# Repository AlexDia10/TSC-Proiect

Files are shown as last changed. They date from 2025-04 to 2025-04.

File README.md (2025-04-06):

# TSC-Proiect

## Schema Bloc



## Bill Of Materials

| Parts | Qty | CHECK_PRICE | DATASHEET |
|---|-----|---|---|
| CHG_LED | 1 | | |
| R1_PINH1, R2_PINH1 | 2 | | |
| S1 | 1 | | |
| EPD_C5 | 1 | | |
| R3 | 1 | | |
| R1_PWRUSB | 1 | | |
| C1, C2, C4_USB, C6, C8, C9, C10, C6_DELAY | 8 | | |
| C3 | 1 | | |
| R4-R10, R_BOOT, R_CHANGE, R_C1, R_RESET| 11  | | |
| C7 | 1 | | |
| J4 | 1 | | |
| R_CAPACITOR | 1 | | |
| C5 | 1 | | |
| EPD_C1–EPD_C12 | 9 | | |
| R2 | 1 | | |
| R1_BAT | 1 | | |
| Q1, Q2 | 2 | | |
| R2_BAT | 1 | | |
| C5_USB | 1 | | |
| C1_BAT, C2_BAT | 4 | | |
| C4 | 1 | | |
| R2-USB, R2-USB1 | 2 | | |
| L1 | 1 | | |
| IC1 | 1 | | |
| BOOT_BUTTON, CHANGE_BUTTON, RESET_BUTTON | 3 | | |
| C10_SUPERCAP | 1 | [SnapEDA](https://www.snapeda.com/parts/PC5H225/Vishay/view-part/?ref=eda) | |
| U3 | 1 | [SnapEDA](https://www.snapeda.com/parts/DS3231SN%23/Analog+Devices/view-part/?ref=eda) | |
| U2 | 1 | [SnapEDA](https://www.snapeda.com/parts/ESP32-C6-WROOM-1-N8/Espressif+Systems/view-part/?ref=eda) | |
| PFMF.050.1 | 1 | | [Datasheet](http://datasheets.avx.com/schottky.pdf) |
| D2, D7 | 2 | | |
| SENSOR2 | 1 | | |
| MCP73831 | 1 | | |
| J1 | 1 | [SnapEDA](https://www.snapeda.com/parts/MAX17048GT10/Analog+Devices/view-part/?ref=eda) | |
| U4 | 1 | [SnapEDA](https://www.snapeda.com/parts/MBR0530/Onsemi/view-part/?ref=eda) | |
| D3, D4, D5 | 3 | [SnapEDA](https://www.snapeda.com/parts/PG81010603MR/Littelfuse/view-part/?ref=eda) | |
| D6, D8–D12 | 6 | | |
| J3 | 1 | | |
| J2 | 1 | [SnapEDA](https://www.snapeda.com/parts/SI1308EDL-T1-GE3/Vishay+Siliconix/view-part/?ref=eda) | |
| Q3 | 1 | | |
| TP1–TP17 | 17  | | |
| D1 | 1 | [SnapEDA](https://www.snapeda.com/parts/USBLC6-2SC6Y/STMicroelectronics/view-part/?ref=eda) | |
| U1 | 1 | [SnapEDA](https://www.snapeda.com/parts/W25Q512JV/Winbond+Electronics/view-part/?ref=eda) | |
| IC4 | | | |

## Specificații Hardware

**🔹 1. Microcontroller – ESP32-C6-WROOM-1-N8**

**CPU:** RISC-V 32-bit, 160 MHz (single-core)

**Memorie:** 320KB SRAM, 512KB ROM, 8MB Flash SPI (W25Q512JVEIQ)

**Conectivitate:** Wi-Fi 6 (300 Mbps), Bluetooth 5 LE (Mesh), Zigbee 3.0

**Periferice:** 4×SPI, 2×I²C, 2×UART, USB 2.0 OTG

**Consum:** 80 mA activ, 1.5 mA sleep, 20 µA deep sleep

**Wake-up:** GPIO, RTC, UART, senzor BME680

**🔹 2. Alimentare**

**Încărcare:** MCP73831 (100–500 mA), LED stare (GPIO18)

**LDO:** BD5229G-TR (eficiență 92%, ripple <50mV)

**Fuel Gauge:** MAX17048 (±1% SOC, alertă critică, 7 µA consum)

**🔹 3. Senzori**

**BME680 (I²C, 0x76):** temp., umiditate, presiune, VOC/eCO₂

Algoritm IAQ (BSEC), compensare termică, calibrare din fabrică

**RTC – DS3231SN#:** ±2ppm, backup cu supercondensator, alarmă, square wave

**🔹 4. Afișaj E-Ink** – 7.5", 800×480 px

**Interfață:** SPI + CS/DC/RST/BUSY

**Consum:** 15–25 mA la refresh, 0 mA static

**Avantaj:** imagine persistentă fără consum

**🔹 5. Interfețe & Stocare**

**USB-C:** alimentare, serial console, DFU update (ESD + Polyfuse 500 mA)

**Qwiic I²C:** extensii senzori/modul

**MicroSD:** loguri/fișiere, SPI/SD

**Flash externă:** W25Q512JVEIQ (quad SPI, aplicații mari)

**🔹 6. Interacțiune**

**Butoane:** 3× tactile (navigare/selectare/back), debouncing HW/SW

**🔹 7. Interfețe Utilizate**

Interfață	Componente
SPI	E-Ink, Flash, SD Card
I²C	BME680, MAX17048, DS3231, Qwiic
GPIO	Butoane, control display
USB	Alimentare, date

## Alocarea pinilor pentru ESP32-C6

| Pin ESP32-C6 | Componentă / Semnal | Descriere |
|---|---|---|
| GPIO1 | I²C SDA (BME680, MAX17048, DS3231, Qwiic) | Linie de date partajată pentru toți senzorii și RTC-ul conectați la magistrala I²C. |
| GPIO2 | I²C SCL (BME680, MAX17048, DS3231, Qwiic) | Linie de clock utilizată pentru sincronizarea comunicației I²C. |
| GPIO5 | SPI MISO (E-Paper) | Primește date de la afișajul E-Paper prin interfața SPI. |
| GPIO6 | SPI MOSI (E-Paper) | Trimite date către afișajul E-Paper prin interfața SPI. |
| GPIO7 | SPI CLK (E-Paper) | Semnal de clock pentru sincronizarea comunicației SPI cu afișajul. |
| GPIO8 | SPI CS (E-Paper) | Semnal Chip Select pentru activarea afișajului E-Paper. |
| GPIO9 | E-Paper DC (Data/Command) | Selectează între trimiterea de date sau comenzi către afișaj. |
| GPIO10 | E-Paper RST | Reset hardware pentru afișajul E-Paper. |
| GPIO11 | E-Paper BUSY | Indică dacă afișajul este ocupat și nu poate primi comenzi. |
| GPIO12 | Button #1 | Buton de control, ex: „Pagina următoare”. |
| GPIO13 | Button #2 | Buton de control, ex: „Pagina anterioară”. |
| GPIO14 | Button #3 | Buton de control, ex: „Meniu” sau „Selectare”. |
| GPIO15 | MAX17048 ALERT (opțional) | Semnal de alertă de la senzorul de baterie (ex: baterie descărcată). |
| GPIO16 | USB D+ (intern la USB PHY) | Linie de semnal diferențial pozitiv pentru conexiunea USB 2.0. |
| GPIO17 | USB D- (intern la USB PHY) | Linie de semnal diferențial negativ pentru conexiunea USB 2.0. |
| GPIO18 | LED de status (opțional) | LED pentru indicarea stărilor (Wi-Fi, încărcare etc.). |
| GPIO19 | SD Card CS (opțional) | Semnal Chip Select pentru cardul microSD. |
| GPIO20 | SD Card MISO (opțional) | Linie de recepție a datelor de la cardul microSD. |
| GPIO21 | SD Card MOSI (opțional) | Linie de transmisie a datelor către cardul microSD. |
| GPIO4 | SD Card CLK (opțional) | Semnal de clock pentru comunicația SPI cu cardul microSD. |

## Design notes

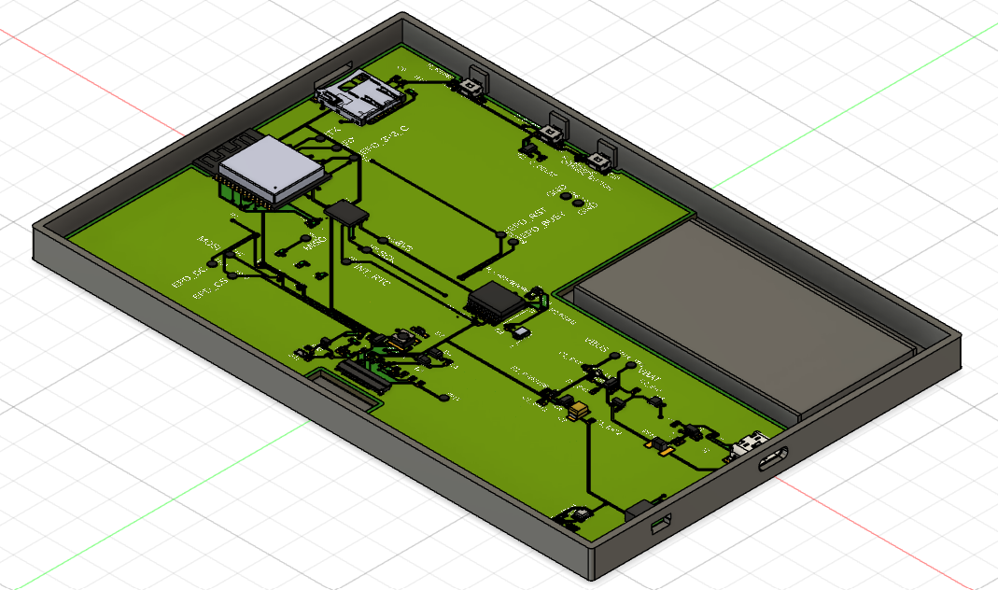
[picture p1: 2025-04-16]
Images/Enclosure.png

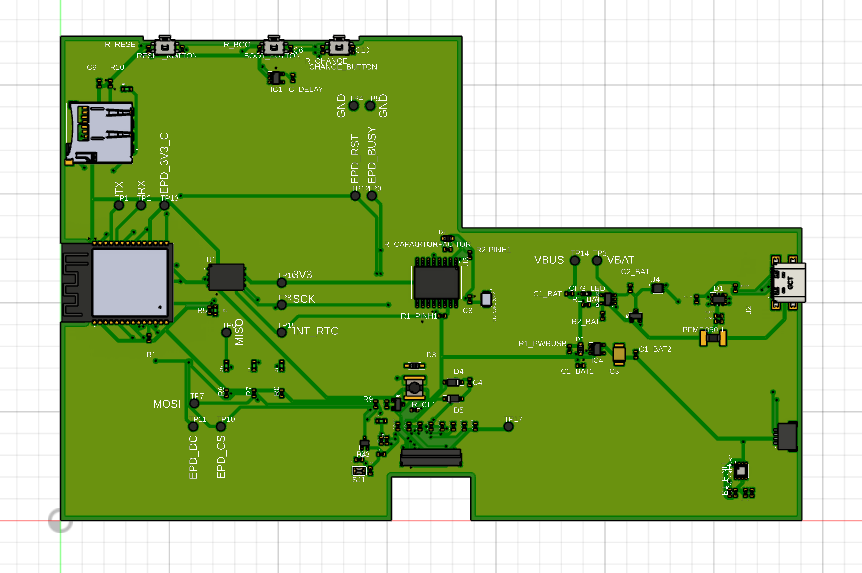
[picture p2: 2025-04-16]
Images/PCB 3D.png

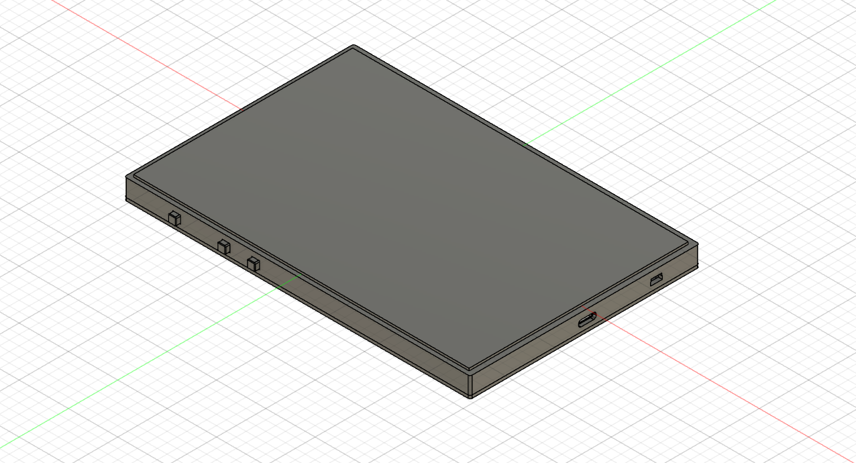
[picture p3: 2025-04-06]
Images/E-bookReader.png

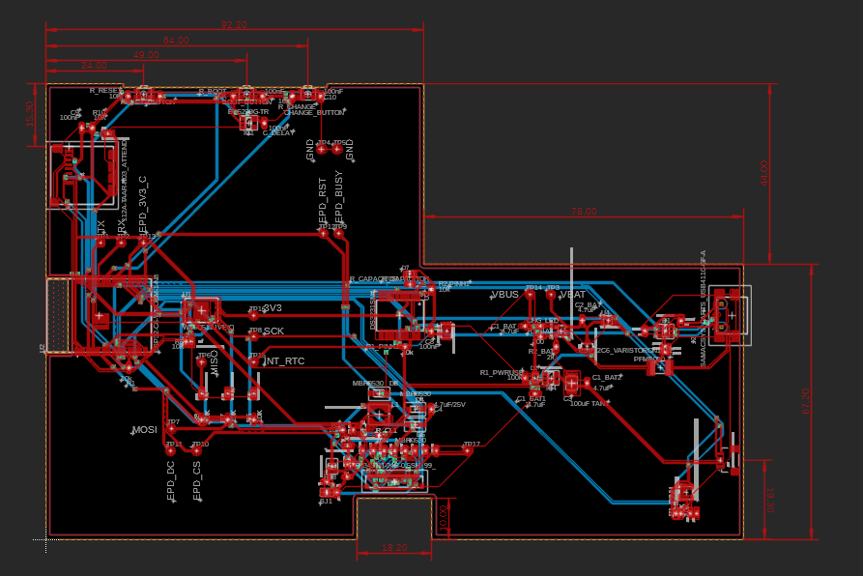
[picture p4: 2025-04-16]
Images/PCB 2D.png

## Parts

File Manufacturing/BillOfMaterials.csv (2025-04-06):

Qty | Value | Device | Package | Parts | Description | ARROW_PART_NUMBER | ARROW_PRICE-STOCK | AVAILABILITY | CENTROID_NOT_SPECIFIED | CHECK_PRICES | COPYRIGHT | DATASHEET | DESCRIPTION | DIGIKEY_DESCRIPTION | DIGIKEY_PART_NUMBER | HEIGHT | LEAD_FREE | MANUFACTURER_NAME | MANUFACTURER_PART_NUMBER | MF | MFR_NAME | MOUSER_PART_NUMBER | MOUSER_PRICE-STOCK | MOUSER_TESTING_PART_NUMBER | MOUSER_TESTING_PRICE-STOCK | MP | MPN | PACKAGE | POPULARITY | PREFIX | PRICE | PROD_ID | PURCHASE-URL | ROHS | SNAPEDA_LINK | SPICEMODEL | SPICEPREFIX | TEMPERATURE_RANGE_HIGH | TEMPERATURE_RANGE_LOW | TP_SIGNAL_NAME | VALUE
1 |  | ADAFRUIT_LEDCHIP-LED0603 | ADAFRUIT_CHIP-LED0603 | CHG_LED | LED
2 |  | ESP32_WROVER_EAGLE-LTSPICE_RR0402 | ESP32_WROVER_EAGLE-LTSPICE_R0402 | R1_PINH, R2-PINH | RESISTOR, European symbol |  |  |  |  |  |  |  |  |  |  |  |  |  |  |  |  |  |  |  |  |  |  |  |  |  |  |  |  |  |  | NONE | R
1 |  | SJ | SJ | SJ1 | SMD solder JUMPER |  |  |  |  |  |  |  |  |  |  |  |  |  |  |  |  |  |  |  |  |  |  |  | 3
1 | 0.1uF/50V | EAGLE-LTSPICE_CC0402 | EAGLE-LTSPICE_C0402 | EPD_C5 | CAPACITOR, European symbol |  |  |  |  |  |  |  |  |  |  |  |  |  |  |  |  |  |  |  |  |  |  |  |  |  |  |  |  |  |  | NONE | C
1 | 0.47 | ESP32_WROVER_EAGLE-LTSPICE_RR0402 | ESP32_WROVER_EAGLE-LTSPICE_R0402 | R3 | RESISTOR, European symbol |  |  |  |  |  |  |  |  |  |  |  |  |  |  |  |  |  |  |  |  |  |  |  |  |  |  |  |  |  |  | NONE | R
1 | 100k | ESP32_WROVER_EAGLE-LTSPICE_RR0402 | ESP32_WROVER_EAGLE-LTSPICE_R0402 | R1_PWRUSB | RESISTOR, European symbol |  |  |  |  |  |  |  |  |  |  |  |  |  |  |  |  |  |  |  |  |  |  |  |  |  |  |  |  |  |  | NONE | R
8 | 100nF | EAGLE-LTSPICE_CC0402 | EAGLE-LTSPICE_C0402 | C1, C2, C4_USB, C6, C8, C9, C10, C_DELAY | CAPACITOR, European symbol |  |  |  |  |  |  |  |  |  |  |  |  |  |  |  |  |  |  |  |  |  |  |  |  |  |  |  |  |  |  | NONE | C
1 | 100uF TANT | RCL_CPOL-EUCT3528 | RCL_CT3528 | C3 | POLARIZED CAPACITOR, European symbol |  |  |  |  |  |  |  |  |  |  |  |  |  |  |  |  |  |  |  |  |  |  |  | 0 |  |  |  |  |  |  |  | C
11 | 10K | ESP32_WROVER_EAGLE-LTSPICE_RR0402 | ESP32_WROVER_EAGLE-LTSPICE_R0402 | R4, R5, R6, R7, R8, R9, R10, R_BOOT, R_CHANGE, R_CL1, R_RESET | RESISTOR, European symbol |  |  |  |  |  |  |  |  |  |  |  |  |  |  |  |  |  |  |  |  |  |  |  |  |  |  |  |  |  |  | NONE | R
3 | 10k | ESP32_WROVER_EAGLE-LTSPICE_RR0402 | ESP32_WROVER_EAGLE-LTSPICE_R0402 | R1, R1_PINH1, R2-PINH1 | RESISTOR, European symbol |  |  |  |  |  |  |  |  |  |  |  |  |  |  |  |  |  |  |  |  |  |  |  |  |  |  |  |  |  |  | NONE | R
1 | 10uF | EAGLE-LTSPICE_CC0402 | EAGLE-LTSPICE_C0402 | C7 | CAPACITOR, European symbol |  |  |  |  |  |  |  |  |  |  |  |  |  |  |  |  |  |  |  |  |  |  |  |  |  |  |  |  |  |  | NONE | C
1 | 112A-TAAR-R03_ATTEND | 112A-TAAR-R03_ATTEND | 112ATAARR03ATTEND | J4 | Micro SD Card Socket, Push-Push Type, Top Mount, SMT, H=1.83mm, 10u |  |  |  |  |  |  |  | Micro SD Card Socket | Push-Push Type | Top Mount | SMT | H=1.83mm | 10u |  |  | 1.9mm |  | ATTEND | 112A-TAAR-R03 ATTEND
1 | 15 | ESP32_WROVER_EAGLE-LTSPICE_RR0402 | ESP32_WROVER_EAGLE-LTSPICE_R0402 | R_CAPACITOR | RESISTOR, European symbol |  |  |  |  |  |  |  |  |  |  |  |  |  |  |  |  |  |  |  |  |  |  |  |  |  |  |  |  |  |  | NONE | R
1 | 1uF | EAGLE-LTSPICE_CC0402 | EAGLE-LTSPICE_C0402 | C5 | CAPACITOR, European symbol |  |  |  |  |  |  |  |  |  |  |  |  |  |  |  |  |  |  |  |  |  |  |  |  |  |  |  |  |  |  | NONE | C
9 | 1uF/50V | EAGLE-LTSPICE_CC0402 | EAGLE-LTSPICE_C0402 | EPD_C1, EPD_C2, EPD_C6, EPD_C7, EPD_C8, EPD_C9, EPD_C10, EPD_C11, EPD_C12 | CAPACITOR, European symbol |  |  |  |  |  |  |  |  |  |  |  |  |  |  |  |  |  |  |  |  |  |  |  |  |  |  |  |  |  |  | NONE | C
1 | 2.2 | ESP32_WROVER_EAGLE-LTSPICE_RR0402 | ESP32_WROVER_EAGLE-LTSPICE_R0402 | R2 | RESISTOR, European symbol |  |  |  |  |  |  |  |  |  |  |  |  |  |  |  |  |  |  |  |  |  |  |  |  |  |  |  |  |  |  | NONE | R
1 | 200 | ESP32_WROVER_EAGLE-LTSPICE_RR0402 | ESP32_WROVER_EAGLE-LTSPICE_R0402 | R1_BAT | RESISTOR, European symbol |  |  |  |  |  |  |  |  |  |  |  |  |  |  |  |  |  |  |  |  |  |  |  |  |  |  |  |  |  |  | NONE | R
2 | 20V/4.2A/52m?/1.4W | ESP32_WROVER_SPARKFUN-DISCRETESEMI_MOSFET_PCH-DMG2305UX-7 | ESP32_WROVER_SPARKFUN-DISCRETESEMI_SOT23-3 | Q1, Q2 | P-channel MOSFETs |  |  |  |  |  |  |  |  |  |  |  |  |  |  |  |  |  |  |  |  |  |  |  |  |  |  | TRAN-14388 |  |  |  |  |  |  |  |  | 20V/4.2A/52m?/1.4W
1 | 2k | ESP32_WROVER_EAGLE-LTSPICE_RR0402 | ESP32_WROVER_EAGLE-LTSPICE_R0402 | R2_BAT | RESISTOR, European symbol |  |  |  |  |  |  |  |  |  |  |  |  |  |  |  |  |  |  |  |  |  |  |  |  |  |  |  |  |  |  | NONE | R
1 | 4.7 uF | EAGLE-LTSPICE_CC0402 | EAGLE-LTSPICE_C0402 | C5_USB | CAPACITOR, European symbol |  |  |  |  |  |  |  |  |  |  |  |  |  |  |  |  |  |  |  |  |  |  |  |  |  |  |  |  |  |  | NONE | C
4 | 4.7uF | EAGLE-LTSPICE_CC0402 | EAGLE-LTSPICE_C0402 | C1_BAT, C1_BAT1, C1_BAT2, C2_BAT | CAPACITOR, European symbol |  |  |  |  |  |  |  |  |  |  |  |  |  |  |  |  |  |  |  |  |  |  |  |  |  |  |  |  |  |  | NONE | C
1 | 4.7uF/25V | EAGLE-LTSPICE_CC0402 | EAGLE-LTSPICE_C0402 | C4 | CAPACITOR, European symbol |  |  |  |  |  |  |  |  |  |  |  |  |  |  |  |  |  |  |  |  |  |  |  |  |  |  |  |  |  |  | NONE | C
2 | 5k1 | ESP32_WROVER_EAGLE-LTSPICE_RR0402 | ESP32_WROVER_EAGLE-LTSPICE_R0402 | R2-USB, R2-USB1 | RESISTOR, European symbol |  |  |  |  |  |  |  |  |  |  |  |  |  |  |  |  |  |  |  |  |  |  |  |  |  |  |  |  |  |  | NONE | R
1 | 744043680IND_4828-WE-TPC_WRE | 744043680IND_4828-WE-TPC_WRE | IND_4828-WE-TPC_WRE | L1 |  |  |  |  |  |  | Copyright (C) 2024 Ultra Librarian. All rights reserved. |  |  |  |  |  |  |  | 744043680 |  | Wurth Electronics
1 | BD5229G-TR | BD5229G-TR | SOT95P280X125-5N | IC1 | Voltage Detector with Adjustable Delay Time: CMOS processes are utilized to develop high precision, low current consumption CMOS reset ICs that allow arbitrary setting of the delay time. The extensive lineup includes both Nch Open Drain and CMOS output types in a wide range of detection voltages (from 2.3V to 6.0V, in 0.1V steps), enabling selection of the ideal solution based on customer requirements. In addition, the entire series is of course both lead-free and RoHS-compliant. |  |  |  |  |  |  |  | Voltage Detector with Adjustable Delay Time: CMOS processes are utilized to develop high precision | low current consumption CMOS reset ICs that allow arbitrary setting of the delay time. The extensive lineup includes both Nch Open Drain and CMOS output types in a wide range of detection voltages (from 2.3V to 6.0V | in 0.1V steps) | enabling selection of the ideal solution based on customer requirements. In addition | the entire series is of course both lead-free and RoHS-compliant. |  |  | 1.25mm |  | ROHM Semiconductor | BD5229G-TR |  |  | 755-BD5229G-TR | https://www.mouser.co.uk/ProductDetail/ROHM-Semiconductor/BD5229G-TR?qs=4kLU8WoGk0vvnhrrYwdszw%3D%3D
3 | BUTTON_CUSYOMV1 | BUTTON_CUSYOMV1 | MYBUTTON | BOOT_BUTTON, CHANGE_BUTTON, RESET_BUTTON
1 | CPH3225A | CPH3225A | CAPCP3225X100N | C10_SUPERCAP | Cap 0.011F 3.3V 1210 Flat Check availability |  |  | Not in stock |  | https://www.snapeda.com/parts/CPH3225A/Seiko+Instruments/view-part/?ref=eda |  |  | 11 mF (EDLC) Supercapacitor 3.3 V 1210 (3225 Metric) - - |  |  |  |  |  |  | Seiko Instruments |  |  |  |  |  | CPH3225A |  | 1210 Seiko |  |  | None |  | https://www.snapeda.com/api/url_track_click_mouser/?unipart_id=562593&manufacturer=Seiko Instruments&part_name=CPH3225A&search_term=None |  | https://www.snapeda.com/parts/CPH3225A/Seiko+Instruments/view-part/?ref=snap
1 | DS3231SN# | DS3231SN# | SOIC127P1032X265-16N | U3 | Real Time Clock Serial 16-Pin SOIC W T/R Check availability |  |  | In Stock |  | https://www.snapeda.com/parts/DS3231SN%23/Analog+Devices/view-part/?ref=eda |  |  | Extremely Accurate I2C-Integrated RTC/TCXO/Crystal |  |  |  |  |  |  | Analog Devices |  |  |  |  |  | DS3231SN# |  | SOIC-16 Maxim |  |  | None |  | https://www.snapeda.com/api/url_track_click_mouser/?unipart_id=99048&manufacturer=Analog Devices&part_name=DS3231SN#&search_term=None |  | https://www.snapeda.com/parts/DS3231SN%23/Analog+Devices/view-part/?ref=snap
1 | ESP32-C6-WROOM-1-N8 | ESP32-C6-WROOM-1-N8 | XCVR_ESP32-C6-WROOM-1-N8 | U2 | Check availability |  |  | In Stock |  | https://www.snapeda.com/parts/ESP32-C6-WROOM-1-N8/Espressif+Systems/view-part/?ref=eda |  |  | Multiprotocol Modules ESP32-C6 module | Wi-Fi 6 in 2.4 GHz band | Bluetooth 5 | Zigbee 3.0 and Thread. ESP34-WROOM Compatible - ENGINEERING SAMPLE |  |  |  |  |  |  | Espressif Systems |  |  |  |  |  | ESP32-C6-WROOM-1-N8 |  | None |  |  | None |  |  |  | https://www.snapeda.com/parts/ESP32-C6-WROOM-1-N8/Espressif+Systems/view-part/?ref=snap
1 | ESP32C6_VARISTORCN1812 | ESP32C6_VARISTORCN1812 | ESP32C6_VARISTOR_CT/CN1812 | PFMF.050.1 | VARISTOR |  |  |  |  |  |  |  |  |  |  |  |  |  |  |  |  |  |  |  |  |  |  |  | 0
2 | ESP32_WROVER_AVX---SD0805S020S1R0_AVX_SD0805S020S1R0_0_0AVX_SD0805S020S1R0_0_0 | ESP32_WROVER_AVX---SD0805S020S1R0_AVX_SD0805S020S1R0_0_0AVX_SD0805S020S1R0_0_0 | ESP32_WROVER_AVX---SD0805S020S1R0_AVX_SD0805S020S1R0_0 | D2, D7 | Schottky Barrier Rectifier Diode |  |  |  | No |  |  | http://datasheets.avx.com/schottky.pdf |  | DIODE SCHOTTKY 20V 1A 0805 | 478-7800-1-ND |  | yes |  |  | AVX |  | 581-SD0805S020S1R0 |  |  |  |  |  | 0805 (2012 metric) |  | D |  |  |  | yes |  |  |  | +125°C | -55°C
1 | ESP32_WROVER_BME680_BME680 | ESP32_WROVER_BME680_BME680 | ESP32_WROVER_BME680_PSON80P300X300X100-8N | SENSOR2 | Integrated Environmental Unit |  |  | Unavailable |  |  |  |  | Integrated Environmental Unit |  |  |  |  |  |  | Bosch Sensortec |  |  |  |  |  | BME680 |  | LGA-8 Bosch Tools |  |  | None
1 | ESP32_WROVER_SPARKFUN-IC-POWER_MCP73831 | ESP32_WROVER_SPARKFUN-IC-POWER_MCP73831 | ESP32_WROVER_SPARKFUN-IC-POWER_SOT23-5 | MCP73831 | MCP73831T Li-Ion, Li-Pol Controller |  |  |  |  |  |  |  |  |  |  |  |  |  |  |  |  |  |  |  |  |  |  |  |  |  |  | IC-09995
1 | FH34SRJ-24S-0.5SH_99_ | FH34SRJ-24S-0.5SH_99_ | FH34SRJ24S05SH99 | J1 | (0.50mm) Surface Mount, Right Angle |  |  |  |  |  |  |  | 24 Position FFC | FPC Connector Contacts | (0.50mm) Surface Mount | Right Angle |  |  | 1.1mm |  | Hirose | FH34SRJ-24S-0.5SH(99) |  |  | 798-FH34SRJ24S05SH99 | https://www.mouser.co.uk/ProductDetail/Hirose-Connector/FH34SRJ-24S-0.5SH99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
1 | MAX17048G+T10 | MAX17048G+T10 | SON50P200X200X80-9N | U4 | Check availability |  |  | In Stock |  | https://www.snapeda.com/parts/MAX17048G+T10/Analog+Devices/view-part/?ref=eda |  |  | 3µA 1-Cell/2-Cell Fuel Gauge with ModelGauge |  |  |  |  |  |  | Analog Devices |  |  |  |  |  | MAX17048G+T10 |  | TDFN-8 Maxim |  |  | None |  | https://www.snapeda.com/api/url_track_click_mouser/?unipart_id=329239&manufacturer=Analog Devices&part_name=MAX17048G+T10&search_term=None |  | https://www.snapeda.com/parts/MAX17048G+T10/Analog+Devices/view-part/?ref=snap
3 | MBR0530 | MBR0530 | SOD3716X135N | D3, D4, D5 | ON SEMICONDUCTOR - MBR0530 - DIODE, SCHOTTKY, 0.5A, 30V, SOD-123 |  |  | In Stock |  | https://www.snapeda.com/parts/MBR0530/Onsemi/view-part/?ref=eda |  |  | Diode Schottky 30 V 500mA Surface Mount SOD-123 |  |  |  |  |  |  | ON Semiconductor |  |  |  |  |  | MBR0530 |  | SOD-123-2 ON Semiconductor |  |  | None |  | https://www.snapeda.com/api/url_track_click_mouser/?unipart_id=179458&manufacturer=ON Semiconductor&part_name=MBR0530&search_term=None |  | https://www.snapeda.com/parts/MBR0530/Onsemi/view-part/?ref=snap
6 | PGB1010603MR | PGB1010603MR | DIOC1608X36N | D6, D8, D9, D10, D11, D12 | Check availability |  |  | In Stock |  | https://www.snapeda.com/parts/PGB1010603MR/Littelfuse/view-part/?ref=eda |  |  | 150V (Typ) Clamp - Ipp Tvs Diode Surface Mount 0603 (1608 Metric) |  |  |  |  |  |  | Littelfuse Inc. |  |  |  |  |  | PGB1010603MR |  | 0603 Littelfuse Inc. |  |  | None |  | https://www.snapeda.com/api/url_track_click_mouser/?unipart_id=5659453&manufacturer=Littelfuse Inc.&part_name=PGB1010603MR&search_term=None |  | https://www.snapeda.com/parts/PGB1010603MR/Littelfuse/view-part/?ref=snap
1 | QWIIC_RIGHT_ANGLE | QWIIC_CONNECTORJS-1MM | JST04_1MM_RA | J3 | SparkFun I2C Standard Qwiic Connector |  |  |  |  |  |  |  |  |  |  |  |  |  |  |  |  |  |  |  |  |  |  |  |  |  |  | CONN-13694 |  |  |  |  |  |  |  |  | QWIIC_RIGHT_ANGLE
1 | SAMACSYS_PARTS_USB4110-GF-A | SAMACSYS_PARTS_USB4110-GF-A | SAMACSYS_PARTS_USB4110GFA | J2 | CONN USB 2.0 TYPE-C R/A SMT |  |  |  |  |  |  |  | CONN USB 2.0 TYPE-C R/A SMT |  |  | 3.26mm |  | GCT (GLOBAL CONNECTOR TECHNOLOGY) | USB4110-GF-A |  |  | 640-USB4110-GF-A | https://www.mouser.co.uk/ProductDetail/GCT/USB4110-GF-A?qs=KUoIvG%2F9IlYiZvIXQjyJeA%3D%3D
1 | SI1308EDL-T1-GE3 | SI1308EDL-T1-GE3 | SOT65P210X110-3N | Q3 | MOSFET N-Ch 30V 1.5A TrenchFET SC70 Vishay Si1308EDL-T1-GE3 N-channel MOSFET Transistor, 1.5 A, 30 V, 3-Pin SC-70 |  |  | In Stock |  | https://www.snapeda.com/parts/SI1308EDL-T1-GE3/Vishay+Siliconix/view-part/?ref=eda |  |  | Si1308EDL-T1-GE3 N-channel MOSFET Transistor | 1.5 A | 30 V | 3-Pin SC-70 | Siliconix / Vishay SI1308EDL-T1-GE3 |  |  |  |  |  |  | Vishay Siliconix |  |  |  |  |  | SI1308EDL-T1-GE3 |  | SOT-323 Vishay Semiconductor |  |  | None |  | https://www.snapeda.com/api/url_track_click_mouser/?unipart_id=274603&manufacturer=Vishay Siliconix&part_name=SI1308EDL-T1-GE3&search_term=None |  | https://www.snapeda.com/parts/SI1308EDL-T1-GE3/Vishay+Siliconix/view-part/?ref=snap
17 | TPTP20R | TPTP20R | TP20R | TP1, TP2, TP3, TP4, TP5, TP6, TP7, TP8, TP9, TP10, TP11, TP12, TP13, TP14, TP15, TP16, TP17 | Test pad |  |  |  |  |  |  |  |  |  |  |  |  |  |  |  |  |  |  |  |  |  |  |  | 2
1 | USBLC6-2SC6Y | USBLC6-2SC6Y | SOT95P280X145-6N | D1 | Low Cap. ESD Protection Auto SOT-23-6 STMicroelectronics USBLC6-2SC6Y, Dual Uni-Directional TVS Diode Array, 6-Pin SOT-23 |  |  | In Stock |  | https://www.snapeda.com/parts/USBLC6-2SC6Y/STMicroelectronics/view-part/?ref=eda |  |  | 17V Clamp 5A (8/20µs) Ipp Tvs Diode Surface Mount SOT-23-6 |  |  |  |  |  |  | STMicroelectronics |  |  |  |  |  | USBLC6-2SC6Y |  | SOT-23-6 STMicroelectronics |  |  | None |  |  |  | https://www.snapeda.com/parts/USBLC6-2SC6Y/STMicroelectronics/view-part/?ref=snap
1 | W25Q512JVEIQ | W25Q512JVEIQ | SON127P600X800X80-9N | U1 | Check availability |  |  | In Stock |  | https://www.snapeda.com/parts/W25Q512JVEIQ/Winbond+Electronics/view-part/?ref=eda |  |  | FLASH - NOR Memory IC 512Mb (64M x 8) SPI - Quad I/O 133 MHz 8-WSON (8x6) |  |  |  |  |  |  | Winbond Electronics |  |  |  |  |  | W25Q512JVEIQ |  | Package |  |  | None |  |  |  | https://www.snapeda.com/parts/W25Q512JVEIQ/Winbond+Electronics/view-part/?ref=snap
1 | XC6220A331MR-G | XC6220A331MR-G | SOT95P280X120-5N | IC4 | LDO Voltage Regulators |  |  |  |  |  |  |  | LDO Voltage Regulators |  |  | 1.2mm |  | Torex | XC6220A331MR-G |  |  | 865-XC6220A331MR-G | https://www.mouser.co.uk/ProductDetail/Torex-Semiconductor/XC6220A331MR-G?qs=AsjdqWjXhJ8ZSWznL1J0gg%3D%3D

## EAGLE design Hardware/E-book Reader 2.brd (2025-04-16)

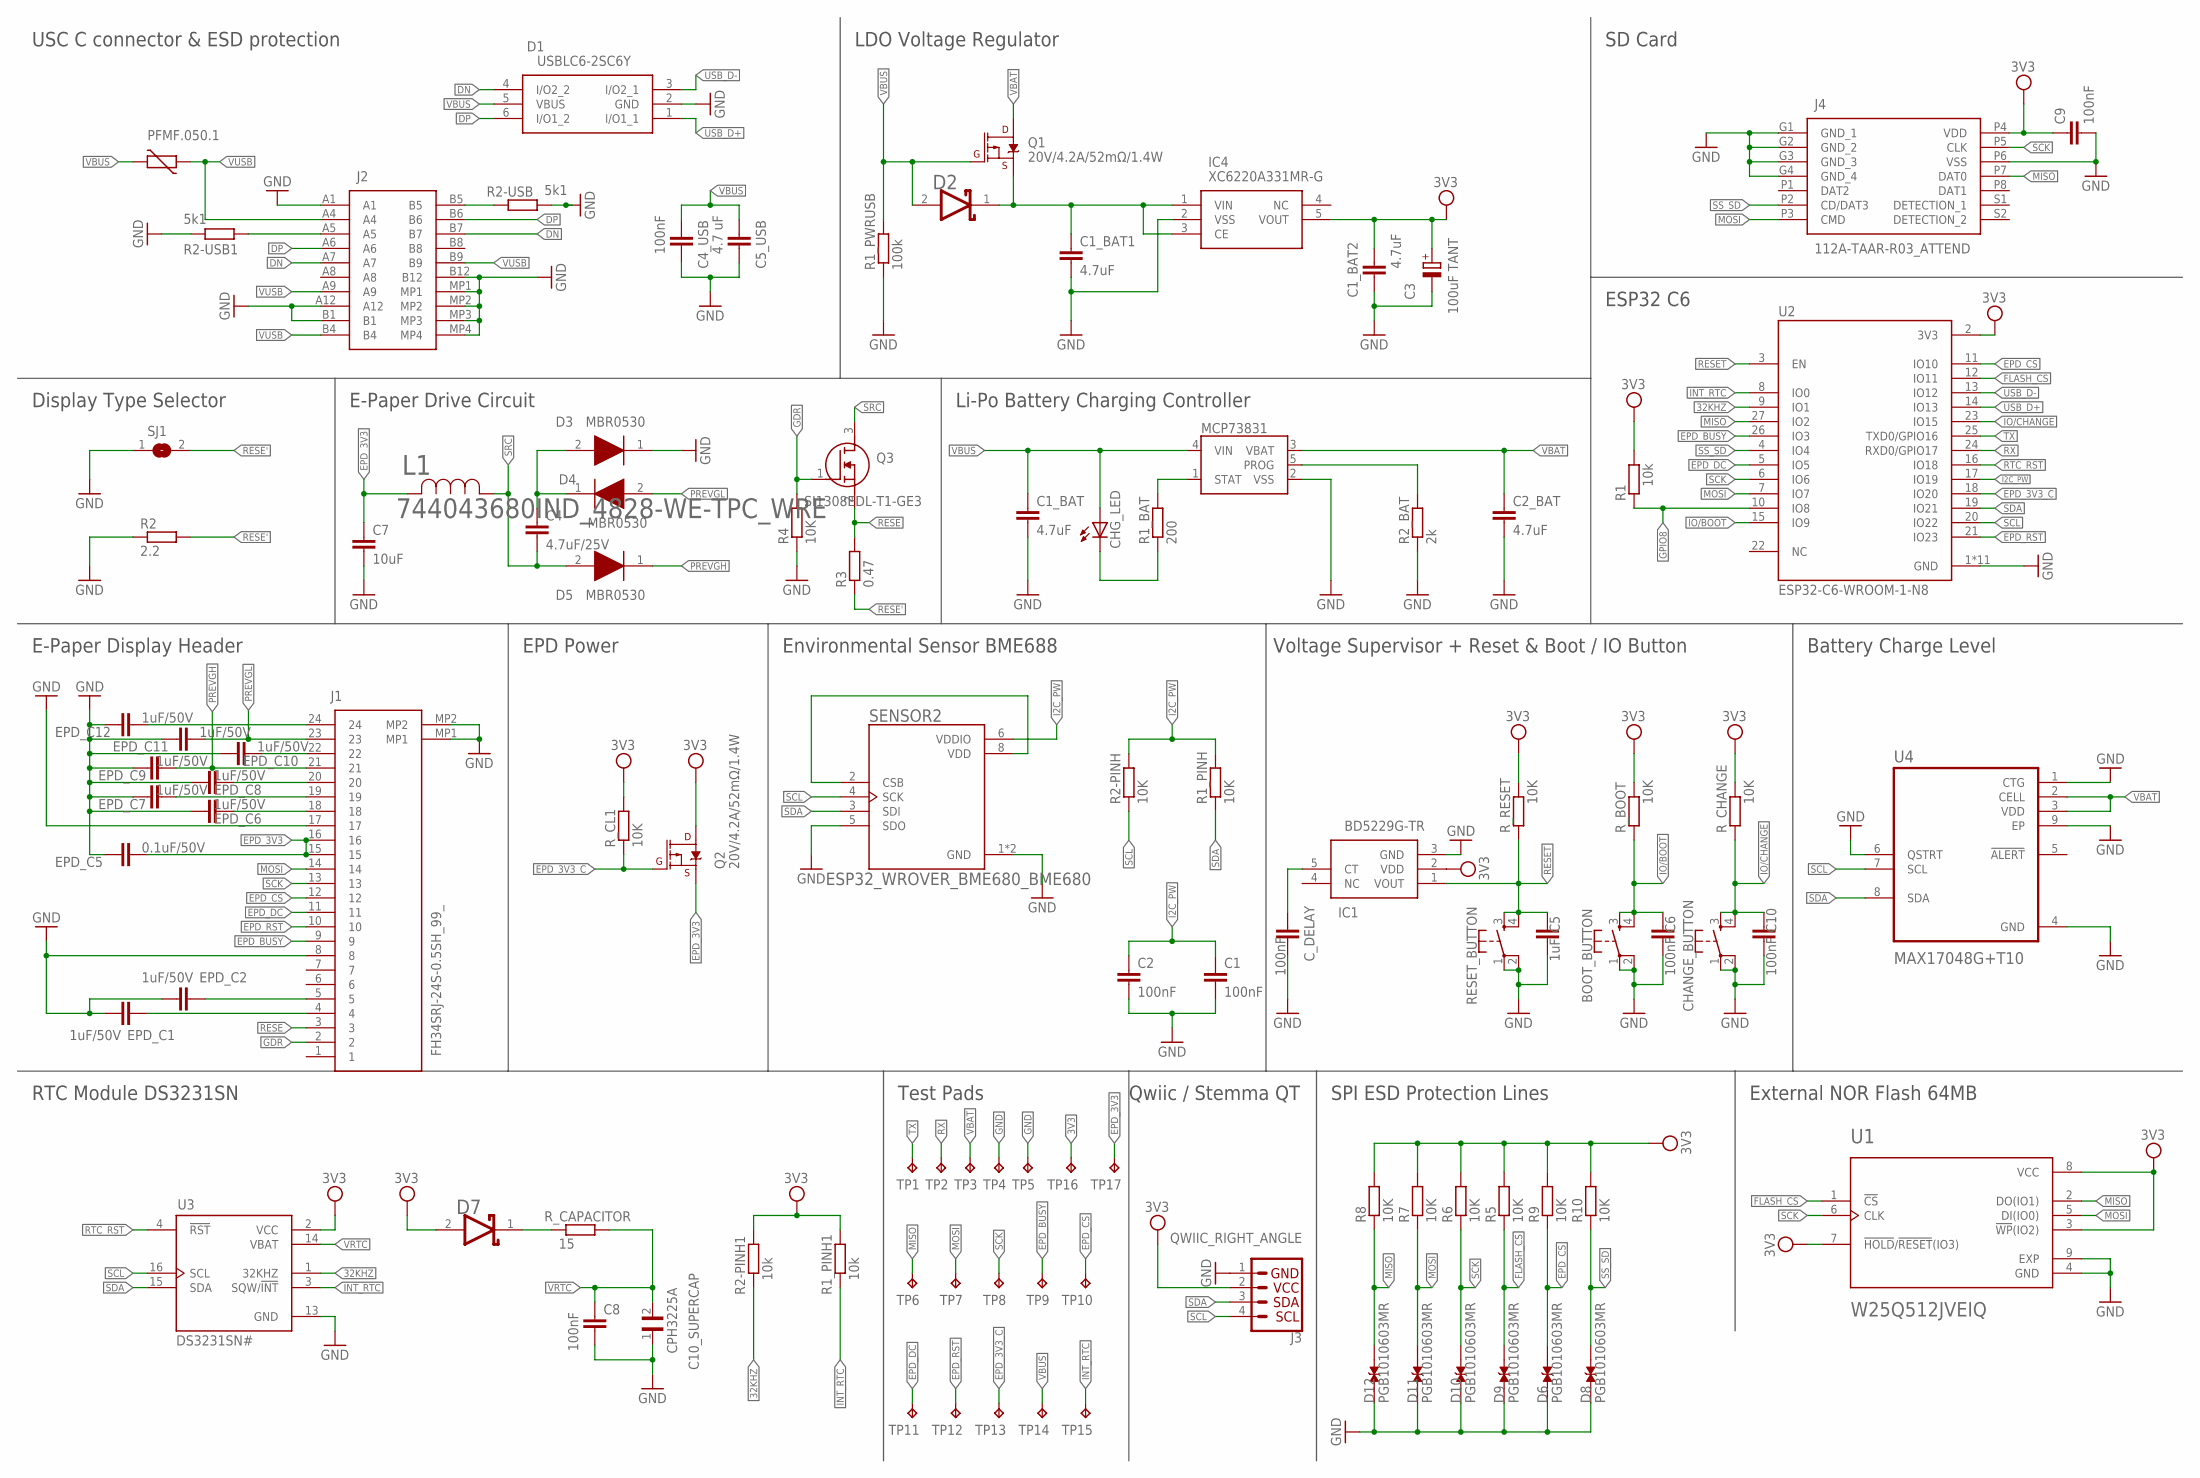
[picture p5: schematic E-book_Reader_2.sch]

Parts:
BOOT_BUTTON: BUTTON_CUSYOMV1; MYBUTTON
C1, C2, C4_USB, C6, C8, C9, C10: 100nF; EAGLE-LTSPICE_C0402
C1_BAT, C1_BAT1, C1_BAT2, C2_BAT: 4.7uF; EAGLE-LTSPICE_C0402
C3: 100uF TANT; RCL_CT3528
C4: 4.7uF/25V; EAGLE-LTSPICE_C0402
C5: 1uF; EAGLE-LTSPICE_C0402
C5_USB: 4.7 uF; EAGLE-LTSPICE_C0402
C7: 10uF; EAGLE-LTSPICE_C0402
C10_SUPERCAP: CPH3225A; CAPCP3225X100N
CHANGE_BUTTON: BUTTON_CUSYOMV1; MYBUTTON
CHG_LED: ADAFRUIT_LEDCHIP-LED0603; ADAFRUIT_CHIP-LED0603
C_DELAY: 100nF; EAGLE-LTSPICE_C0402
D1: USBLC6-2SC6Y; SOT95P280X145-6N
D2, D7: ESP32_WROVER_AVX---SD0805S020S1R0_AVX_SD0805S020S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; ESP32_WROVER_AVX---SD0805S020S1R0_AVX_SD0805S020S1R0_0
D3, D4, D5: MBR0530; SOD3716X135N
D6, D8, D9, D10, D11, D12: PGB1010603MR; DIOC1608X36N
EPD_C1, EPD_C2, EPD_C6, EPD_C7, EPD_C8, EPD_C9, EPD_C10, EPD_C11, EPD_C12: 1uF/50V; EAGLE-LTSPICE_C0402
EPD_C5: 0.1uF/50V; EAGLE-LTSPICE_C0402
IC1: BD5229G-TR; SOT95P280X125-5N
IC4: XC6220A331MR-G; SOT95P280X120-5N
J1: FH34SRJ-24S-0.5SH_99_; FH34SRJ24S05SH99
J2: SAMACSYS_PARTS_USB4110-GF-A; SAMACSYS_PARTS_USB4110GFA
J3: QWIIC_RIGHT_ANGLE; JST04_1MM_RA
J4: 112A-TAAR-R03_ATTEND; 112ATAARR03ATTEND
L1: 744043680IND_4828-WE-TPC_WRE; IND_4828-WE-TPC_WRE
MCP73831: ESP32_WROVER_SPARKFUN-IC-POWER_MCP73831; ESP32_WROVER_SPARKFUN-IC-POWER_SOT23-5
PFMF.050.1: ESP32C6_VARISTORCN1812; ESP32C6_VARISTOR_CT/CN1812
Q1, Q2: 20V/4.2A/52mΩ/1.4W; ESP32_WROVER_SPARKFUN-DISCRETESEMI_SOT23-3
Q3: SI1308EDL-T1-GE3; SOT65P210X110-3N
R1, R1_PINH1, R2-PINH1: 10k; ESP32_WROVER_EAGLE-LTSPICE_R0402
R1_BAT: 200; ESP32_WROVER_EAGLE-LTSPICE_R0402
R1_PINH, R2-PINH, R4, R5, R6, R7, R8, R9, R10: 10K; ESP32_WROVER_EAGLE-LTSPICE_R0402
R1_PWRUSB: 100k; ESP32_WROVER_EAGLE-LTSPICE_R0402
R2: 2.2; ESP32_WROVER_EAGLE-LTSPICE_R0402
R2-USB, R2-USB1: 5k1; ESP32_WROVER_EAGLE-LTSPICE_R0402
R2_BAT: 2k; ESP32_WROVER_EAGLE-LTSPICE_R0402
R3: 0.47; ESP32_WROVER_EAGLE-LTSPICE_R0402
RESET_BUTTON: BUTTON_CUSYOMV1; MYBUTTON
R_BOOT: 10K; ESP32_WROVER_EAGLE-LTSPICE_R0402
R_CAPACITOR: 15; ESP32_WROVER_EAGLE-LTSPICE_R0402
R_CHANGE: 10K; ESP32_WROVER_EAGLE-LTSPICE_R0402
R_CL1: 10K; ESP32_WROVER_EAGLE-LTSPICE_R0402
R_RESET: 10K; ESP32_WROVER_EAGLE-LTSPICE_R0402
SENSOR2: ESP32_WROVER_BME680_BME680; ESP32_WROVER_BME680_PSON80P300X300X100-8N
SJ1: SJ
TP1, TP2, TP3, TP4, TP5, TP6, TP7, TP8, TP9, TP10, TP11, TP12, TP13, TP14, TP15, TP16, TP17: TPTP20R; TP20R
U1: W25Q512JVEIQ; SON127P600X800X80-9N
U2: ESP32-C6-WROOM-1-N8; XCVR_ESP32-C6-WROOM-1-N8
U3: DS3231SN#; SOIC127P1032X265-16N
U4: MAX17048G+T10; SON50P200X200X80-9N

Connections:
3V3: C1_BAT2.1, C3.+, C9.1, D7.2 (ANODE), IC1.2 (VDD), IC4.5 (VOUT), J3.2, J4.P4 (VDD), Q2.3 (D), R1.2, R1_PINH1.2, R2-PINH1.2, R5.2, R6.2, R7.2, R8.2, R9.2, R10.2, R_BOOT.2, R_CHANGE.2, R_CL1.2, R_RESET.2, TP16.TP, U1.3 (!WP!(IO2)), U1.7 (!HOLD!/!RESET!(IO3)), U1.8 (VCC), U2.2 (3V3), U3.2 (VCC)
32KHZ: R2-PINH1.1, U2.9 (IO1), U3.1 (32KHZ)
DN: D1.4 (I/O2_2), J2.A7, J2.B7
DP: D1.6 (I/O1_2), J2.A6, J2.B6
EPD_3V3: C7.1, EPD_C5.1, J1.15, J1.16, L1.2, Q2.2 (S), TP17.TP
EPD_3V3_C: Q2.1 (G), R_CL1.1, TP13.TP, U2.18 (IO20)
EPD_BUSY: J1.9, TP9.TP, U2.26 (IO3)
EPD_CS: D6.2, J1.12, R9.1, TP10.TP, U2.11 (IO10)
EPD_DC: J1.11, TP11.TP, U2.5 (IO5)
EPD_RST: J1.10, TP12.TP, U2.21 (IO23)
FLASH_CS: D9.2, R5.1, U1.1 (!CS), U2.12 (IO11)
GDR: J1.2, Q3.1 (G), R4.2
GND: BOOT_BUTTON.1, BOOT_BUTTON.2, C1.2, C1_BAT.2, C1_BAT1.2, C1_BAT2.2, C2.2, C2_BAT.2, C3.-, C4_USB.2, C5.2, C5_USB.2, C6.2, C7.2, C8.2, C9.2, C10.2, C10_SUPERCAP.1, CHANGE_BUTTON.1, CHANGE_BUTTON.2, C_DELAY.2, D1.2 (GND), D3.1 (K), D6.1, D8.1, D9.1, D10.1, D11.1, D12.1, EPD_C1.2, EPD_C2.2, EPD_C5.2, EPD_C6.2, EPD_C7.2, EPD_C8.2, EPD_C9.2, EPD_C10.2, EPD_C11.2, EPD_C12.2, IC1.3 (GND), IC4.2 (VSS), J1.8, J1.17, J1.MP1, J1.MP2, J2.A1, J2.A12, J2.B1, J2.B12, J2.MP1, J2.MP2, J2.MP3, J2.MP4, J3.1, J4.G1 (GND_1), J4.G2 (GND_2), J4.G3 (GND_3), J4.G4 (GND_4), J4.P6 (VSS), MCP73831.2 (VSS), R1_PWRUSB.1, R2.1, R2-USB.2, R2-USB1.1, R2_BAT.1, R4.1, RESET_BUTTON.1, RESET_BUTTON.2, SENSOR2.1 (GND), SENSOR2.5 (SDO), SENSOR2.7 (GND), SJ1.1, TP4.TP, TP5.TP, U1.4 (GND), U1.9 (EXP), U2.1 (GND), U2.28 (GND), U2.29_1 (GND), U2.29_2 (GND), U2.29_3 (GND), U2.29_4 (GND), U2.29_5 (GND), U2.29_6 (GND), U2.29_7 (GND), U2.29_8 (GND), U2.29_9 (GND), U3.13 (GND), U4.1 (CTG), U4.4 (GND), U4.6 (QSTRT), U4.9 (EP)
GPIO8: R1.1, U2.10 (IO8)
I2C_PW: C1.1, C2.1, R1_PINH.2, R2-PINH.2, SENSOR2.6 (VDDIO), U2.17 (IO19)
INT_RTC: R1_PINH1.1, TP15.TP, U2.8 (IO0), U3.3 (SQW/!INT)
IO/BOOT: BOOT_BUTTON.3, BOOT_BUTTON.4, C6.1, R_BOOT.1, U2.15 (IO9)
IO/CHANGE: C10.1, CHANGE_BUTTON.3, CHANGE_BUTTON.4, R_CHANGE.1, U2.23 (IO15)
MISO: D12.2, J4.P7 (DAT0), R8.1, TP6.TP, U1.2 (DO(IO1)), U2.27 (IO2)
MOSI: D11.2, J1.14, J4.P3 (CMD), R7.1, TP7.TP, U1.5 (DI(IO0)), U2.7 (IO7)
unnamed: C1_BAT1.1, D2.1 (CATHODE), IC4.1 (VIN), IC4.3 (CE), Q1.2 (S)
unnamed: EPD_C12.1, J1.24
unnamed: J2.A5, R2-USB1.2
unnamed: C4.1, D3.2 (A), D4.1 (K)
unnamed: CHG_LED.C, R1_BAT.1
unnamed: MCP73831.1 (STAT), R1_BAT.2
unnamed: MCP73831.5 (PROG), R2_BAT.2
unnamed: J2.B5, R2-USB.1
unnamed: C_DELAY.1, IC1.5 (CT)
unnamed: EPD_C2.1, J1.5
unnamed: D7.1 (CATHODE), R_CAPACITOR.1
unnamed: EPD_C10.1, J1.22
unnamed: EPD_C1.1, J1.4
unnamed: EPD_C8.1, J1.20
unnamed: SENSOR2.2 (CSB), SENSOR2.8 (VDD)
unnamed: EPD_C7.1, J1.19
unnamed: EPD_C6.1, J1.18
PREVGH: D5.1 (K), EPD_C9.1, J1.21
PREVGL: D4.2 (A), EPD_C11.1, J1.23
RESE: J1.3, Q3.2 (S), R3.2
RESE': R2.2, R3.1, SJ1.2
RESET: C5.1, IC1.1 (VOUT), RESET_BUTTON.3, RESET_BUTTON.4, R_RESET.1, U2.3 (EN)
RTC_RST: U2.16 (IO18), U3.4 (!RST)
RX: TP2.TP, U2.24 (RXD0/GPIO17)
SCK: D10.2, J1.13, J4.P5 (CLK), R6.1, TP8.TP, U1.6 (CLK), U2.6 (IO6)
SCL: J3.4, R2-PINH.1, SENSOR2.4 (SCK), U2.20 (IO22), U3.16 (SCL), U4.7 (SCL)
SDA: J3.3, R1_PINH.1, SENSOR2.3 (SDI), U2.19 (IO21), U3.15 (SDA), U4.8 (SDA)
SRC: C4.2, D5.2 (A), L1.1, Q3.3 (D)
SS_SD: D8.2, J4.P2 (CD/DAT3), R10.1, U2.4 (IO4)
TX: TP1.TP, U2.25 (TXD0/GPIO16)
USB_D+: D1.1 (I/O1_1), U2.14 (IO13)
USB_D-: D1.3 (I/O2_1), U2.13 (IO12)
VBAT: C2_BAT.1, MCP73831.3 (VBAT), Q1.3 (D), TP3.TP, U4.2 (CELL), U4.3 (VDD)
VBUS: C1_BAT.1, C4_USB.1, C5_USB.1, CHG_LED.A, D1.5 (VBUS), D2.2 (ANODE), MCP73831.4 (VIN), PFMF.050.1.2, Q1.1 (G), R1_PWRUSB.2, TP14.TP
VRTC: C8.1, C10_SUPERCAP.2, R_CAPACITOR.2, U3.14 (VBAT)
VUSB: J2.A4, J2.A9, J2.B4, J2.B9, PFMF.050.1.1

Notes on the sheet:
USC C connector & ESD protection
LDO Voltage Regulator
SD Card
Display Type Selector
E-Paper Drive Circuit
Li-Po Battery Charging Controller
ESP32 C6
E-Paper Display Header
EPD Power
Environmental Sensor BME688
Voltage Supervisor + Reset & Boot / IO Button
Battery Charge Level
RTC Module DS3231SN
Test Pads
Qwiic / Stemma QT
SPI ESD Protection Lines
External NOR Flash 64MB

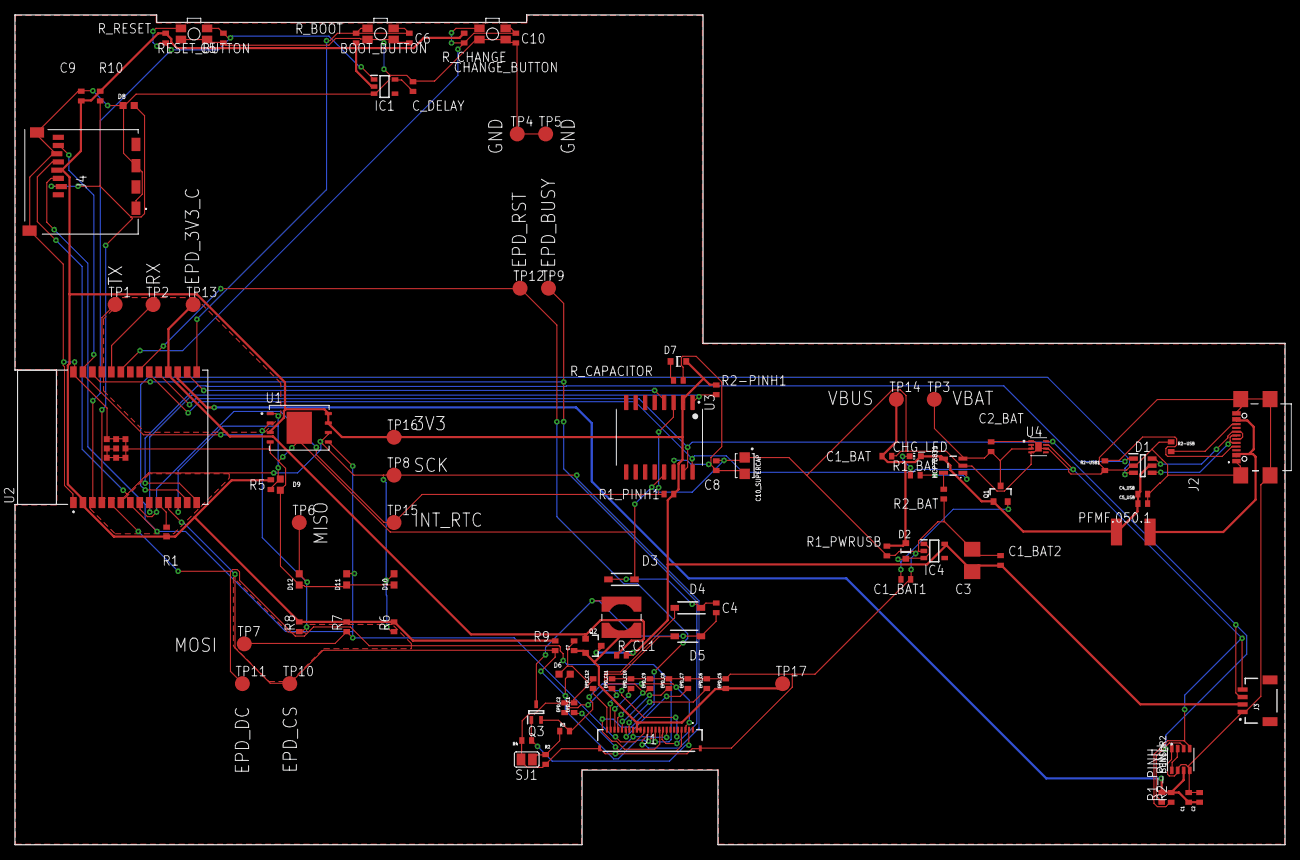
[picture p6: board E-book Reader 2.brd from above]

Board: 2 copper layers, 170.2 x 111.2 mm, 103 parts (0 on the bottom side), 56 nets.

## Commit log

2025-04-06 Hardware upload
    [E-bookReader.brd, E-bookReader.sch]
2025-04-06 Manufacturing upload
    [BillOfMaterials.csv, PickAndPlace.csv]

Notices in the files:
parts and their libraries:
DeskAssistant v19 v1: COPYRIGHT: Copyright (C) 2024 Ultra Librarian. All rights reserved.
